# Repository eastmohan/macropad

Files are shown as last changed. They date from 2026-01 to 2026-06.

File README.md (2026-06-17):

# macropad
macropad with 6 keys, 1 rotary encoder, 1 0.91" oled, 2 micro eleds

rotary encoder: set to control volume  <br />
keys: mapped to skip/pause songs, turn LEDs and OLED on/off, copy, and paste.  <br />
oled displays current song + artist  <br />
micro eleds and the XIAO onboard LED all cycle a rainbow (synced)  <br />  <br />
to use the oled for now playing, first install rainmeter and then add the skin in this repo. you may need a chrome extension to get now playing info from chrome. it should refresh every few seconds and save the song and artist to a txt file in the rainmeter folder, which the python script reads and prints to the oled.  <br />  <br />
for personal use  <br />
not for commercial use  <br />

**Demo:** https://www.youtube.com/watch?v=B0LNcNpDYtY </br><br>
**Updates since recording:**</br><br>
  Upper left button:
-   On/off button for the LEDs and OLED
-   Upon pressing to turn off, OLED displays a message and LEDs turn off. After a short delay, the OLED powers off as well.
-   When powering on, LEDs turn on immediately and OLED displays a message before going back to song information <br><br>
  OLED:
    Now shows messages for button presses:
-    KEY: Copy
-    KEY: Paste
-    KEY: LEDs ON/OFF
-    KEY: Prev Track
-    KEY: Play/Pause
-  KEY: Next Track

**BOM:** <br />
SK6812MINI-E mini LED - 2 <br />
Resistor_SMD:R_0402_1005Metric <br />
Button_Switch_Keyboard:SW_Cherry_MX_1.00u_PCB - 6 <br />
Keycaps - 6 <br />
Rotary_Encoder:RotaryEncoder_Alps_EC11E-Switch_Vertical_H20mm - 1 <br />
RF_Module:MCU_Seeed_ESP32C3 - 1 <br />
4pinoled:SSD1306-0.91-OLED-4pin-128x32 - 1 <br />
<br />
M3 x 16mm screws - 4 <br/>
M3 heat set inserts - 4 <br/>















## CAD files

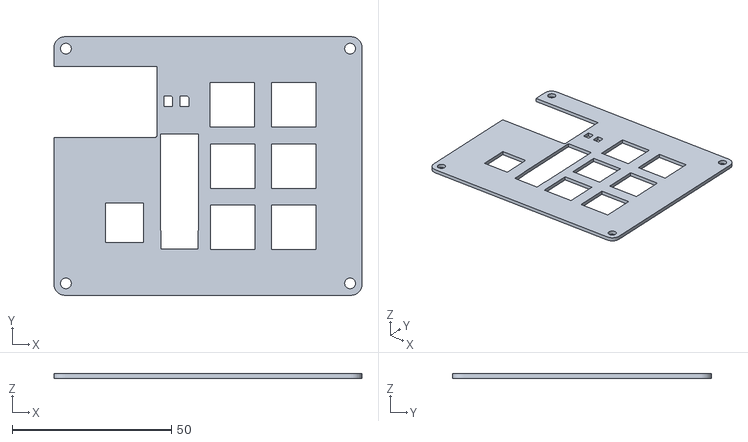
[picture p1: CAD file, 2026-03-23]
CAD/bottom_updated_clearances.stl
96.8 x 81.3 x 1.50

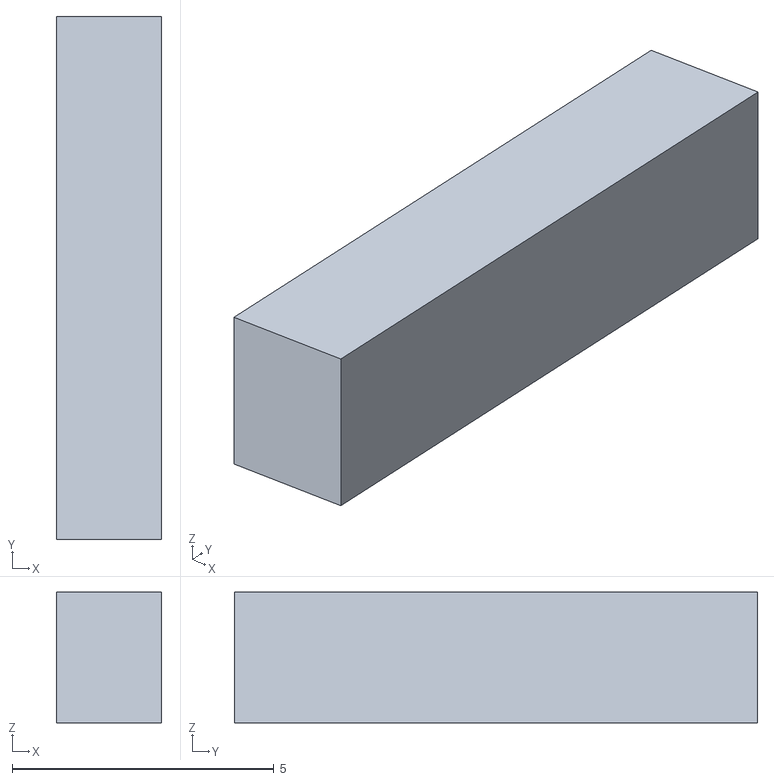
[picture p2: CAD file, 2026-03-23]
CAD/oled_standoff.stl
2.00 x 10.0 x 2.50

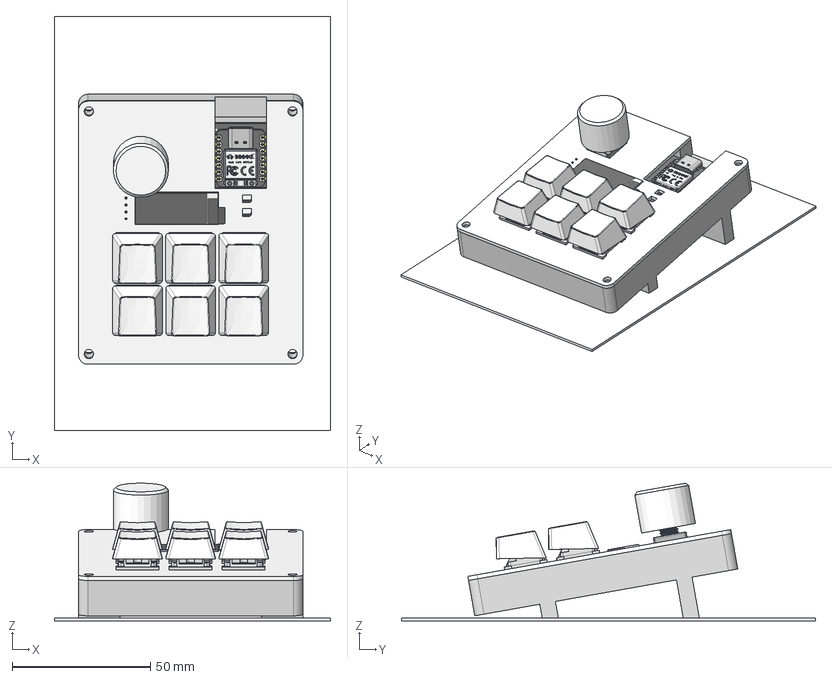
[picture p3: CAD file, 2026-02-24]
CAD/macropad final.step
100.0 x 150.0 x 49.9 mm
original_macropad_copper
original_macropad_silkscreen
original_macropad_silkscreen_1
original_macropad_soldermask
original_macropad_soldermask_1
original_macropad_PCB
type-c v2
smd_button v3
DOUT
DIN
VSS
VDD
smd_button v3(Mirror)
旋转编码器
OLED_0.91_128x32
Pin Header 4 x 1 TH 2.54mm Pitch
RESC-0603 x 13
2SD0601A
Button x 6
Pins x 6
1x1 R1 v23 x 6
1x1 R2 v8 x 6
1x1 R3 v8 x 6
1x1 R4 v6 x 6
1x1.5 R1 v4 x 6
1x1.5 R3 v6 x 6
1x1.5 R4 v5 x 6
1x1.5 R2 v5 x 6
1x1.25 R1 v7 x 6
1x1.25 R2 v4 x 6
1x1.25 R4 v6 x 6
1x1.25 R3 v5 x 6
1x1.75 R1 v6 x 6
1x1.75 R2 v4 x 6
1x1.75 R4 v4 x 6
1x1.75 R3 v5 x 6
1x2 R1 v6 x 6
1x2 R4 v6 x 6
1x2 R3 v6 x 6
1x2 R2 v6 x 6
1x2.25 R1 v6 x 6
1x2.25 R2 v6 x 6
1x2.25 R4 v6 x 6
1x2.25 R3 v6 x 6
1x2.5 R1 v5 x 6
1x2.5 R2 v7 x 6
1x2.5 R3 v6 x 6
1x2.5 R4 v5 x 6
1x2.75 R1 v3 x 6
1x6.25 R1 v6 x 6
1x2.75 R4 v3 x 6
1x2.75 R3 v3 x 6
1x2.75 R2 v4 x 6
SK6812 MINI E-LED

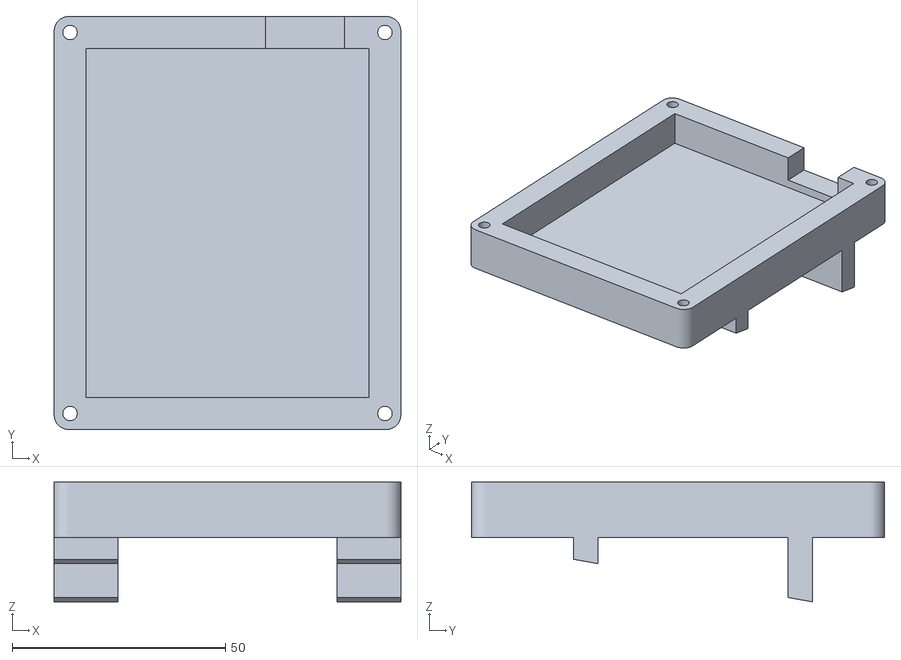
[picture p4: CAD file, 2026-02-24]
CAD/bottom.stl
81.3 x 96.8 x 28.1

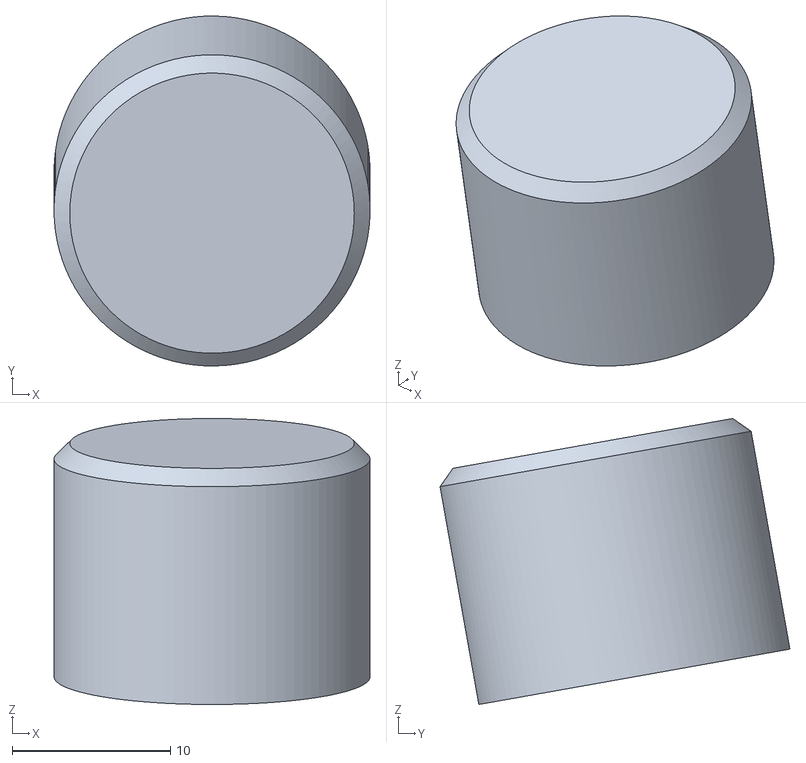
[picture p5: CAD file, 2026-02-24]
CAD/dial.stl
20.0 x 22.1 x 18.1

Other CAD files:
CAD/top.stl

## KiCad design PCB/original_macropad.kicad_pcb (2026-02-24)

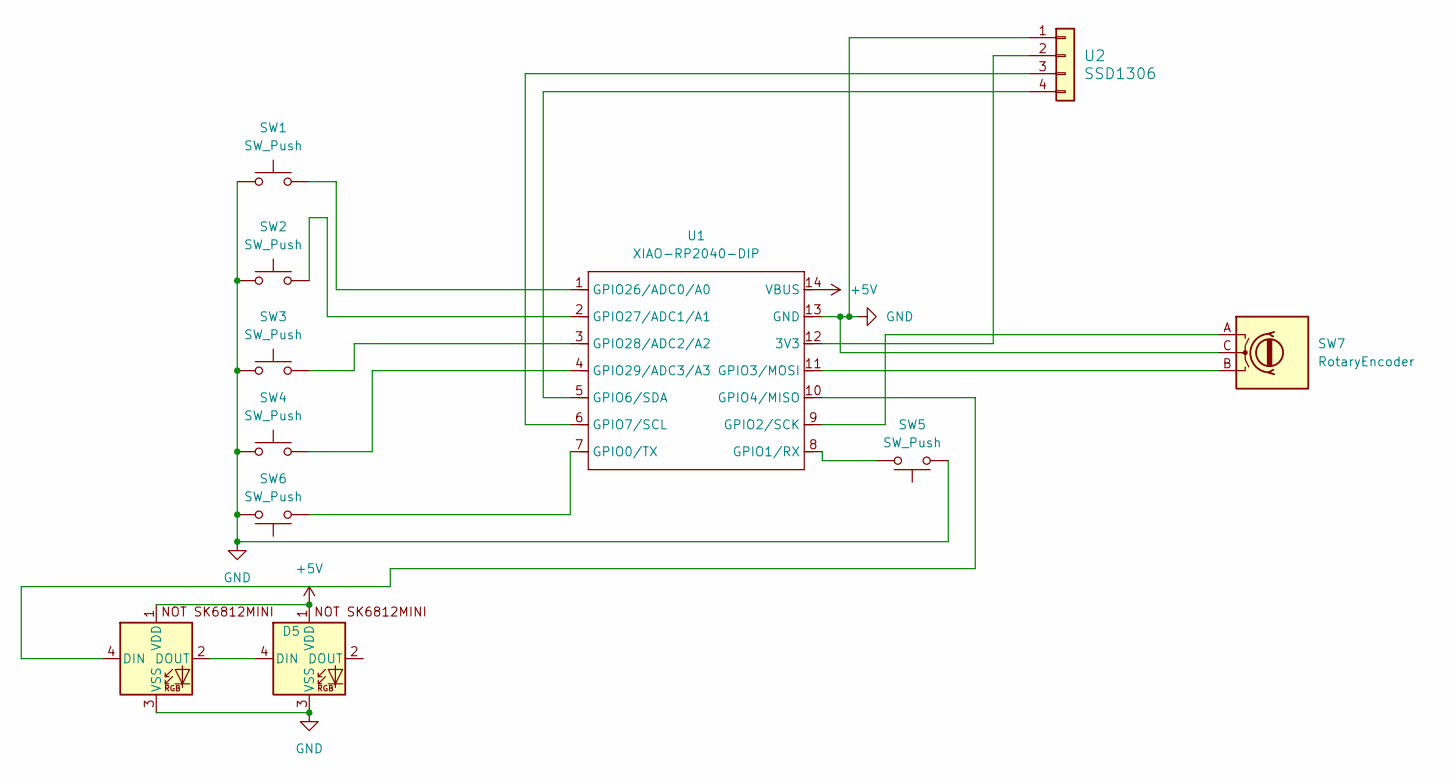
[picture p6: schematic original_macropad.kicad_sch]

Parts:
D4, D5: SK6812MINI; SK6812MINI-E_fixed
SW1, SW2, SW3, SW4, SW5, SW6: SW_Push; SW_Cherry_MX_1.00u_PCB
SW7: RotaryEncoder; RotaryEncoder_Alps_EC11E-Switch_Vertical_H20mm
U1: XIAO-RP2040-DIP
U2: SSD1306; SSD1306-0.91-OLED-4pin-128x32

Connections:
+5V: D4.1 (VDD), D5.1 (VDD), U1.14 (VBUS)
GND: D4.3 (VSS), D5.3 (VSS), SW1.1, SW2.1, SW3.1, SW4.1, SW5.1, SW6.2, SW7.C, U1.13 (GND), U2.1
unnamed: D4.4 (DIN), D5.2 (DOUT)
unnamed: D5.4 (DIN), U1.10 (GPIO4/MISO)
unnamed: U1.12 (3V3), U2.2
unnamed: SW6.1, U1.7 (GPIO0/TX)
unnamed: SW5.2, U1.8 (GPIO1/RX)
unnamed: SW7.A, U1.9 (GPIO2/SCK)
unnamed: SW7.B, U1.11 (GPIO3/MOSI)
unnamed: U1.5 (GPIO6/SDA), U2.4
unnamed: U1.6 (GPIO7/SCL), U2.3
unnamed: SW1.2, U1.1 (GPIO26/ADC0/A0)
unnamed: SW2.2, U1.2 (GPIO27/ADC1/A1)
unnamed: SW3.2, U1.3 (GPIO28/ADC2/A2)
unnamed: SW4.2, U1.4 (GPIO29/ADC3/A3)

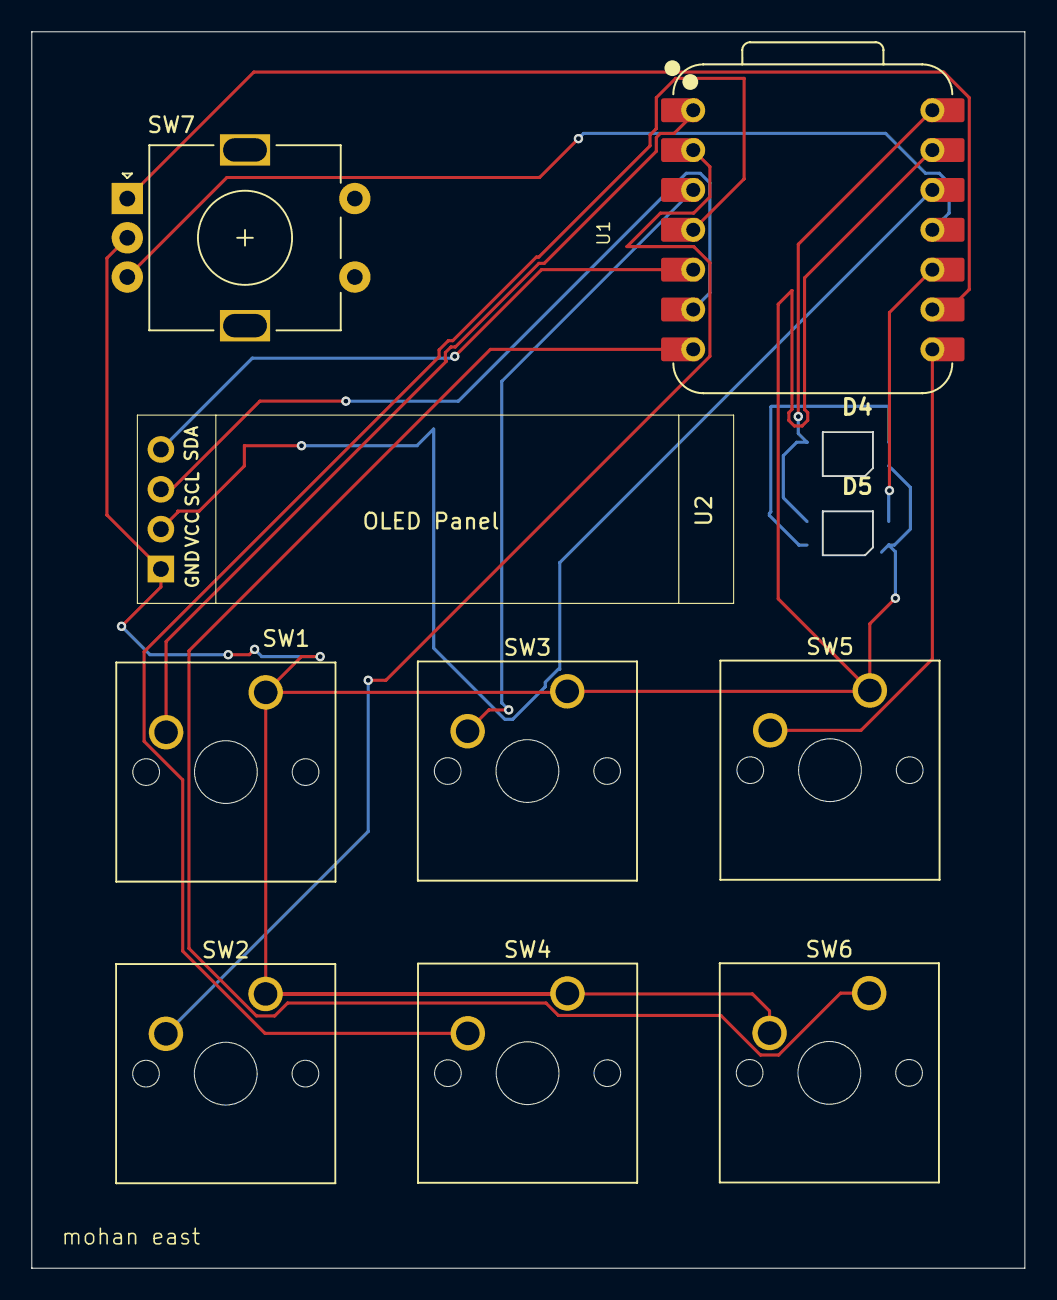
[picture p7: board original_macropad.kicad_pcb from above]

Board: 2 copper layers, 63.3 x 78.8 mm, 11 parts (0 on the bottom side), 15 nets.

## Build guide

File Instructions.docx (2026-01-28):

Instructions:

Download the Kicad files (schematic if you want to edit, PCB if you just want to get it made). Solder all components. 3D print the top and bottom parts of the case, place the PCB inside, and put the top on.

On your computer, install rainmeter. Then, create a folder in the Rainmeter folder (in documents) called NowPlayingToText. Inside, put NowPlayingToText.ini. Within that folder, make a @Resources folder. In there, put WriteTrack.lua and NowPlaying.txt (you don’t have to make the txt because it will automatically be made). Then, plug in the microcontroller and upload the python script. Feel free to modify the key mapping to be useful for your workflow. That’s all!

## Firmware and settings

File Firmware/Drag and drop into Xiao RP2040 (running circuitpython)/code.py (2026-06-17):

# code.py — Macropad firmware for Seeed XIAO RP2040

import board
import busio
import digitalio
import neopixel
import rotaryio
import time
import usb_hid
import usb_cdc

import adafruit_ssd1306
from adafruit_hid.consumer_control import ConsumerControl
from adafruit_hid.consumer_control_code import ConsumerControlCode
from adafruit_hid.keyboard import Keyboard
from adafruit_hid.keyboard_layout_us import KeyboardLayoutUS
from adafruit_hid.keycode import Keycode

# ── HID ──────────────────────────────────────────────────────────────────
cc     = ConsumerControl(usb_hid.devices)
kbd    = Keyboard(usb_hid.devices)
layout = KeyboardLayoutUS(kbd)

# ── MACRO KEYS ────────────────────────────────────────────────────────────
KEY_PINS = (
    board.A0,
    board.A1,
    board.A2,
    board.A3,
    board.TX,
    board.RX,
)

KEY_ACTIONS = (
    ("key", (Keycode.CONTROL, Keycode.C)),   # Copy
    ("cc",  ConsumerControlCode.SCAN_PREVIOUS_TRACK),
    ("key", (Keycode.CONTROL, Keycode.V)),   # Paste
    ("cc",  ConsumerControlCode.PLAY_PAUSE),
    ("cc",  ConsumerControlCode.SCAN_NEXT_TRACK),
    ("toggle_led", None),
)

KEY_LABELS = {
    (Keycode.CONTROL, Keycode.C): "Copy",
    (Keycode.CONTROL, Keycode.V): "Paste",
    (Keycode.CONTROL, Keycode.Z): "Undo",
    ConsumerControlCode.SCAN_PREVIOUS_TRACK: "Prev Track",
    ConsumerControlCode.SCAN_NEXT_TRACK: "Next Track",
    ConsumerControlCode.PLAY_PAUSE: "Play / Pause",
}

_keys = []
for _p in KEY_PINS:
    _b = digitalio.DigitalInOut(_p)
    _b.direction = digitalio.Direction.INPUT
    _b.pull = digitalio.Pull.UP
    _keys.append(_b)

_key_prev = [False] * len(_keys)

def _send_key(action):
    global _leds_enabled
    global _oled_sleep

    kind, val = action

    if kind == "cc":
        cc.send(val)
        show_overlay(KEY_LABELS.get(val, "Media"))

    elif kind == "key":
        kbd.press(*val)
        kbd.release_all()
        show_overlay(KEY_LABELS.get(val, "Key Combo"))

    elif kind == "toggle_led":
        _leds_enabled = not _leds_enabled

        if _leds_enabled:
            _oled_sleep = False
            show_overlay("LEDs ON")

        else:
            show_overlay("LEDs OFF")

            pixels.fill((0, 0, 0))
            pixels.show()

            onboard.fill((0, 0, 0))
            onboard.show()

            _oled_sleep = True

# ── ROTARY ENCODER ────────────────────────────────────────────────────────
encoder = rotaryio.IncrementalEncoder(board.MOSI, board.SCK)
_enc_last = encoder.position

# ── SK6812 MINI LEDs (macropad) ──────────────────────────────────────────
pixels = neopixel.NeoPixel(
    board.MISO,
    2,
    brightness=0.5,
    auto_write=False,
    pixel_order=neopixel.GRB
)

# ── Onboard XIAO RP2040 LED ──────────────────────────────────────────────
onboard = neopixel.NeoPixel(
    board.NEOPIXEL,
    1,
    brightness=0.2,
    auto_write=False,
    pixel_order=neopixel.GRB
)

def _wheel(pos):
    pos = pos % 255

    if pos < 85:
        return (255 - pos * 3, pos * 3, 0, 0)
    elif pos < 170:
        pos -= 85
        return (0, 255 - pos * 3, pos * 3, 0)
    else:
        pos -= 170
        return (pos * 3, 0, 255 - pos * 3, 0)

_hue = 0
_leds_enabled = True
_oled_sleep = False

# ── OLED SSD1306 128x32 ───────────────────────────────────────────────────
_i2c = busio.I2C(board.SCL, board.SDA)
oled  = adafruit_ssd1306.SSD1306_I2C(128, 32, _i2c)

_MAX_ARTIST = 21
_MAX_SONG   = 10

def _oled_refresh(artist, song):
    oled.fill(0)
    oled.text(song[:_MAX_SONG], 0, 0, 1)

    src_w = _MAX_SONG * 6
    pixels_on = []

    for y in range(8):
        for x in range(src_w):
            if oled.pixel(x, y):
                pixels_on.append((x, y))

    oled.fill(0)
    oled.text(artist[:_MAX_ARTIST], 0, 0, 1)

    for (x, y) in pixels_on:
        dx = x * 2
        dy = y * 2 + 16
        if dy + 1 < 32:
            oled.pixel(dx, dy, 1)
            oled.pixel(dx + 1, dy, 1)
            oled.pixel(dx, dy + 1, 1)
            oled.pixel(dx + 1, dy + 1, 1)

    oled.show()

_oled_refresh("Now Playing", "Waiting...")

# ── SCROLLING ─────────────────────────────────────────────────────────────
_SCROLL_SPD = 0.22
_PAUSE_LEN  = 1.8

_line1_txt    = "Now Playing"
_scroll_txt   = "Waiting..."
_scroll_pos   = 0
_scroll_state = "pause_start"
_scroll_ts    = 0.0

def _visible():
    if len(_scroll_txt) <= _MAX_SONG:
        return _scroll_txt
    return _scroll_txt[_scroll_pos:_scroll_pos + _MAX_SONG]

def set_now_playing(raw):
    global _line1_txt, _scroll_txt, _scroll_pos, _scroll_state, _scroll_ts

    raw = raw.strip()

    if " - " in raw:
        title, artist = raw.split(" - ", 1)
        _line1_txt  = artist[:_MAX_ARTIST]
        _scroll_txt = title
    else:
        _line1_txt  = "Now Playing"
        _scroll_txt = raw

    _scroll_pos   = 0
    _scroll_state = "pause_start"
    _scroll_ts    = time.monotonic()

    _oled_refresh(_line1_txt, _visible())

def _tick_scroll(now):
    global _scroll_pos, _scroll_state, _scroll_ts

    if len(_scroll_txt) <= _MAX_SONG:
        return

    max_pos = len(_scroll_txt) - _MAX_SONG

    if _scroll_state == "pause_start":
        if now - _scroll_ts >= _PAUSE_LEN:
            _scroll_state = "scrolling"
            _scroll_ts = now

    elif _scroll_state == "scrolling":
        if now - _scroll_ts >= _SCROLL_SPD:
            _scroll_pos = min(_scroll_pos + 1, max_pos)
            _oled_refresh(_line1_txt, _visible())
            _scroll_ts = now

            if _scroll_pos >= max_pos:
                _scroll_state = "pause_end"

    elif _scroll_state == "pause_end":
        if now - _scroll_ts >= _PAUSE_LEN:
            _scroll_pos = 0
            _scroll_state = "pause_start"
            _scroll_ts = now
            _oled_refresh(_line1_txt, _visible())

# ── OLED OVERLAY SYSTEM ───────────────────────────────────────────────────
_overlay_text = None
_overlay_until = 0
_overlay_active = False

def show_overlay(text):
    
    

    
    global _overlay_text, _overlay_until, _overlay_active

    _overlay_text = text
    _overlay_until = time.monotonic() + 1.5
    _overlay_active = True

    oled.fill(0)
    oled.text("KEY:", 0, 0, 1)
    oled.text(text[:21], 0, 16, 1)
    oled.show()

# ── SERIAL ────────────────────────────────────────────────────────────────
_serial = usb_cdc.data

# ── MAIN LOOP ─────────────────────────────────────────────────────────────
while True:
    _now = time.monotonic()

    # Rotary encoder → volume
    _pos = encoder.position
    if _pos != _enc_last:
        _delta = _pos - _enc_last
        _code  = (ConsumerControlCode.VOLUME_INCREMENT
                  if _delta > 0 else ConsumerControlCode.VOLUME_DECREMENT)

        for _ in range(min(abs(_delta), 5)):
            cc.send(_code)

        _enc_last = _pos

    # Macro keys
    for _i, _btn in enumerate(_keys):
        _pressed = not _btn.value
        if _pressed and not _key_prev[_i]:
            _send_key(KEY_ACTIONS[_i])
        _key_prev[_i] = _pressed

    # NowPlaying from PC
    if _serial and _serial.in_waiting:
        _line = _serial.readline()
        if _line:
            set_now_playing(_line.decode("utf-8"))

        # ── LEDs (rainbow synced) ───────────────────────────────────────────
    if _leds_enabled:
        _hue = (_hue + 1) % 255
        color = _wheel(_hue)

        pixels[0] = color
        pixels[1] = color
        pixels.show()

        onboard[0] = color
        onboard.show()

    # ── OLED update logic ────────────────────────────────────────────────
    if _overlay_active:
        if time.monotonic() >= _overlay_until:
            _overlay_active = False

            if _oled_sleep:
                oled.fill(0)
                oled.show()
            else:
                _oled_refresh(_line1_txt, _visible())

    elif _oled_sleep:
        pass

    else:
        _tick_scroll(_now)

    time.sleep(0.005)

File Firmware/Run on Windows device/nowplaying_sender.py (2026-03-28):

#!/usr/bin/env python3
"""
nowplaying_sender.py — runs on your Windows PC in the background.
Watches Rainmeter's NowPlaying.txt and pushes updates to the macropad
over USB serial whenever the track changes.

Requirements:
    pip install pyserial watchdog

Run once at startup (add to Task Scheduler or your shell's startup script).
"""

import os
import sys
import time
import threading

import serial
import serial.tools.list_ports
from watchdog.observers import Observer
from watchdog.events import FileSystemEventHandler


# ── Path to your Rainmeter NowPlaying file ────────────────────────────────
# This uses your Windows username automatically — no editing needed
# as long as Rainmeter is in the default Documents location.
NOWPLAYING_PATH = r"C:\Users\eastm\OneDrive\Documents\Rainmeter\Skins\NowPlayingToText\@Resources\NowPlaying.txt"

# ── Serial port settings ──────────────────────────────────────────────────
BAUD = 115200
# Leave as None to auto-detect, or hardcode e.g. "COM5" if auto-detect fails.
MANUAL_PORT = "COM8"


# ── Port detection ────────────────────────────────────────────────────────
def find_macropad_port() -> str | None:
    """
    CircuitPython with usb_cdc.enable(data=True) creates TWO serial ports.
    The data port (CDC2) is the one we want — it's usually the higher COM number.
    """
    ports = sorted(serial.tools.list_ports.comports(), key=lambda p: p.device)
    cp_ports = [p for p in ports if "CircuitPython" in (p.description or "")]

    if not cp_ports:
        return None

    print("Found CircuitPython port(s):")
    for p in cp_ports:
        print(f"  {p.device}  —  {p.description}")

    # CDC2 (data port) is typically described with "CDC2" or is the last/higher port
    data_ports = [p for p in cp_ports if "CDC2" in (p.description or "")]
    if data_ports:
        return data_ports[0].device

    # Fallback: if there are two ports, the second one is the data port
    if len(cp_ports) >= 2:
        return cp_ports[1].device

    # Only one port found — use it (works if console is disabled or same port)
    return cp_ports[0].device


# ── Sender ────────────────────────────────────────────────────────────────
class NowPlayingSender:
    def __init__(self, port: str):
        self.port = port
        self.ser: serial.Serial | None = None
        self._lock = threading.Lock()
        self._connect()

    def _connect(self):
        try:
            self.ser = serial.Serial(self.port, BAUD, timeout=1)
            print(f"✓ Connected to macropad on {self.port}")
        except serial.SerialException as e:
            print(f"✗ Could not open {self.port}: {e}")
            self.ser = None

    def send(self, text: str):
        if not self.ser:
            self._connect()
            if not self.ser:
                return
        with self._lock:
            try:
                payload = (text.strip() + "\n").encode("utf-8")
                self.ser.write(payload)
                print(f"→ Sent: {text.strip()!r}")
            except serial.SerialException:
                print("Connection lost — will retry on next update.")
                self.ser = None

    def send_file(self):
        """Read NowPlaying.txt and send its contents."""
        if not os.path.exists(NOWPLAYING_PATH):
            print(f"File not found: {NOWPLAYING_PATH}")
            return
        try:
            with open(NOWPLAYING_PATH, "r", encoding="utf-8", errors="replace") as f:
                content = f.read().strip()
            if content:
                self.send(content)
        except OSError as e:
            print(f"Could not read file: {e}")


# ── Watchdog event handler ────────────────────────────────────────────────
class FileChangeHandler(FileSystemEventHandler):
    def __init__(self, sender: NowPlayingSender):
        super().__init__()
        self.sender = sender
        self._last_send = 0.0

    def on_modified(self, event):
        # Only react to our specific file
        if not event.is_directory and os.path.abspath(event.src_path) == os.path.abspath(NOWPLAYING_PATH):
            # Debounce: Rainmeter sometimes fires multiple events per update
            now = time.time()
            if now - self._last_send > 0.5:
                self._last_send = now
                time.sleep(0.1)   # tiny delay so Rainmeter finishes writing
                self.sender.send_file()


# ── Main ──────────────────────────────────────────────────────────────────
def main():
    # 1. Validate file path
    if not os.path.exists(NOWPLAYING_PATH):
        print(f"\n⚠  NowPlaying.txt not found at:\n   {NOWPLAYING_PATH}")
        print("\nMake sure the Rainmeter NowPlayingToText skin is active.")
        print("If your Rainmeter folder is in a different location, edit NOWPLAYING_PATH in this script.")
        sys.exit(1)

    # 2. Find the macropad serial port
    port = MANUAL_PORT or find_macropad_port()
    if not port:
        print("\n⚠  Macropad not found on any serial port.")
        print("Make sure:")
        print("  1. The XIAO is plugged in via USB")
        print("  2. boot.py is on the CIRCUITPY drive (enables the data port)")
        print("  3. CircuitPython is installed on the XIAO")
        print("\nAvailable ports:")
        for p in serial.tools.list_ports.comports():
            print(f"  {p.device}  —  {p.description}")
        print("\nIf you can see the port above, set  MANUAL_PORT = 'COMx'  at the top of this script.")
        sys.exit(1)

    # 3. Connect and send the current track immediately
    sender = NowPlayingSender(port)
    sender.send_file()

    # 4. Watch for future changes
    watch_dir = os.path.dirname(NOWPLAYING_PATH)
    handler   = FileChangeHandler(sender)
    observer  = Observer()
    observer.schedule(handler, path=watch_dir, recursive=False)
    observer.start()

    print(f"\nWatching: {NOWPLAYING_PATH}")
    print("Press Ctrl+C to stop.\n")

    try:
        while True:
            time.sleep(1)
    except KeyboardInterrupt:
        pass
    finally:
        observer.stop()
        observer.join()
        if sender.ser:
            sender.ser.close()
        print("Stopped.")


if __name__ == "__main__":
    main()

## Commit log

2026-01-28 create pcb folder
2026-01-28 move to folder
    [assembly.step]
2026-02-24 add updated kicad files
    [original_macropad.kicad_pcb, original_macropad.kicad_sch]
2026-03-23 updated cad
    [bottom_updated_clearances.stl, oled_standoff.stl]
